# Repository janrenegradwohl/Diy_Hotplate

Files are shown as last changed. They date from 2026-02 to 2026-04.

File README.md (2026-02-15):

# DIY HotPlate

I needed a reflow hot plate for reflow-soldering, so I decided to build one myself. I used an STM32F301, which is connected to the PC via a USB-UART bridge. I’ve already ordered the second revision of the hardware.

I’m currently working on the hardware and firmware. PC software for control and data plotting will follow soon.

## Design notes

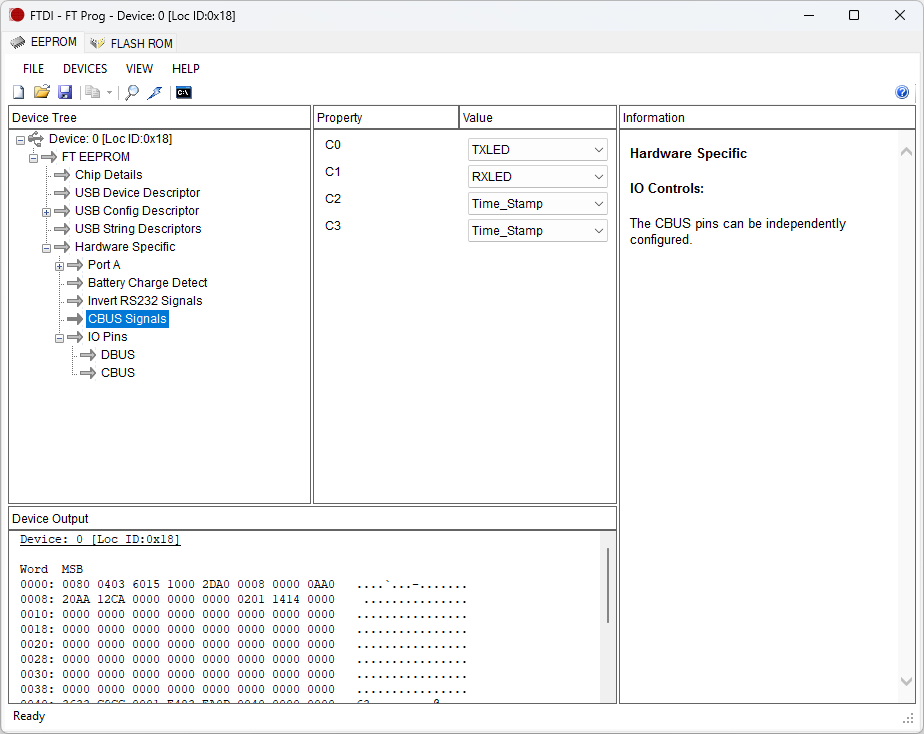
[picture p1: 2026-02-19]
pictures/FT_Prog.png

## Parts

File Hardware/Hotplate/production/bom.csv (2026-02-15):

Designator | Footprint | Quantity | Value | LCSC Part #
C1, C10, C2, C9 | 0603 | 4 | 100nF
C11, C6 | 0603 | 2 | 1uF
C12, C13 | 0603 | 2 | 47pF
C3 | 0603 | 1 | 10nF
C4, C5 | 0603 | 2 | 1uF | C15849
C7 | 0805 | 1 | 10uF | C15849
C8 | 0805 | 1 | 1uF | C15849
D1 | 0603 | 1 | 5V
D2, D3 | 0603 | 2 | LED
D4 | 0603 | 1 | 3V3
D5 | 0603 | 1 | PB7
D6 | 0603 | 1 | PA15
D7 | D_DO-15_P10.16mm_Horizontal | 1 | D_Schottky
IC1 | TO254P470X1016X1965-3P | 1 | TL783CKCSE3
IC2 | SOT95P270X145-5N | 1 | MCP1402T-E_OT
IC4 | SOP64P599X175-20N | 1 | FT231XS-U
J1, J2 | PinHeader_1x04_P2.54mm_Vertical | 2 | Conn_01x04_Pin
J10 | PinHeader_1x02_P2.54mm_Vertical | 1 | 5V
J3 | PinHeader_1x04_P2.54mm_Vertical | 1 | I2C2
J4 | SolderWire-1.5sqmm_1x01_D1.7mm_OD3mm | 1 | VCC
J5 | SolderWire-1.5sqmm_1x01_D1.7mm_OD3mm | 1 | GND
J8 | GSB1C41110SSHR | 1 | GSB1C41110SSHR
J9 | PinHeader_1x05_P2.54mm_Vertical | 1 | SPI3
Q1 | BSC146N10LS5ATMA1 | 1 | BSC146N10LS5ATMA1
R1, R17, R8, R9 | 0603 | 4 | 1k
R11, R15, R16 | 0603 | 3 | 270
R12, R13 | 0603 | 2 | 27
R4, R5 | 0805 | 2 | 15kR | C17475
R6 | 0805 | 1 | 4.7k
R7 | 0805 | 1 | 3k
SW1, SW2, SW3, SW4 | SW_PUSH_6mm | 4 | SW_Push
U1 | LQFP-32_7x7mm_P0.8mm | 1 | STM32F301K6Tx

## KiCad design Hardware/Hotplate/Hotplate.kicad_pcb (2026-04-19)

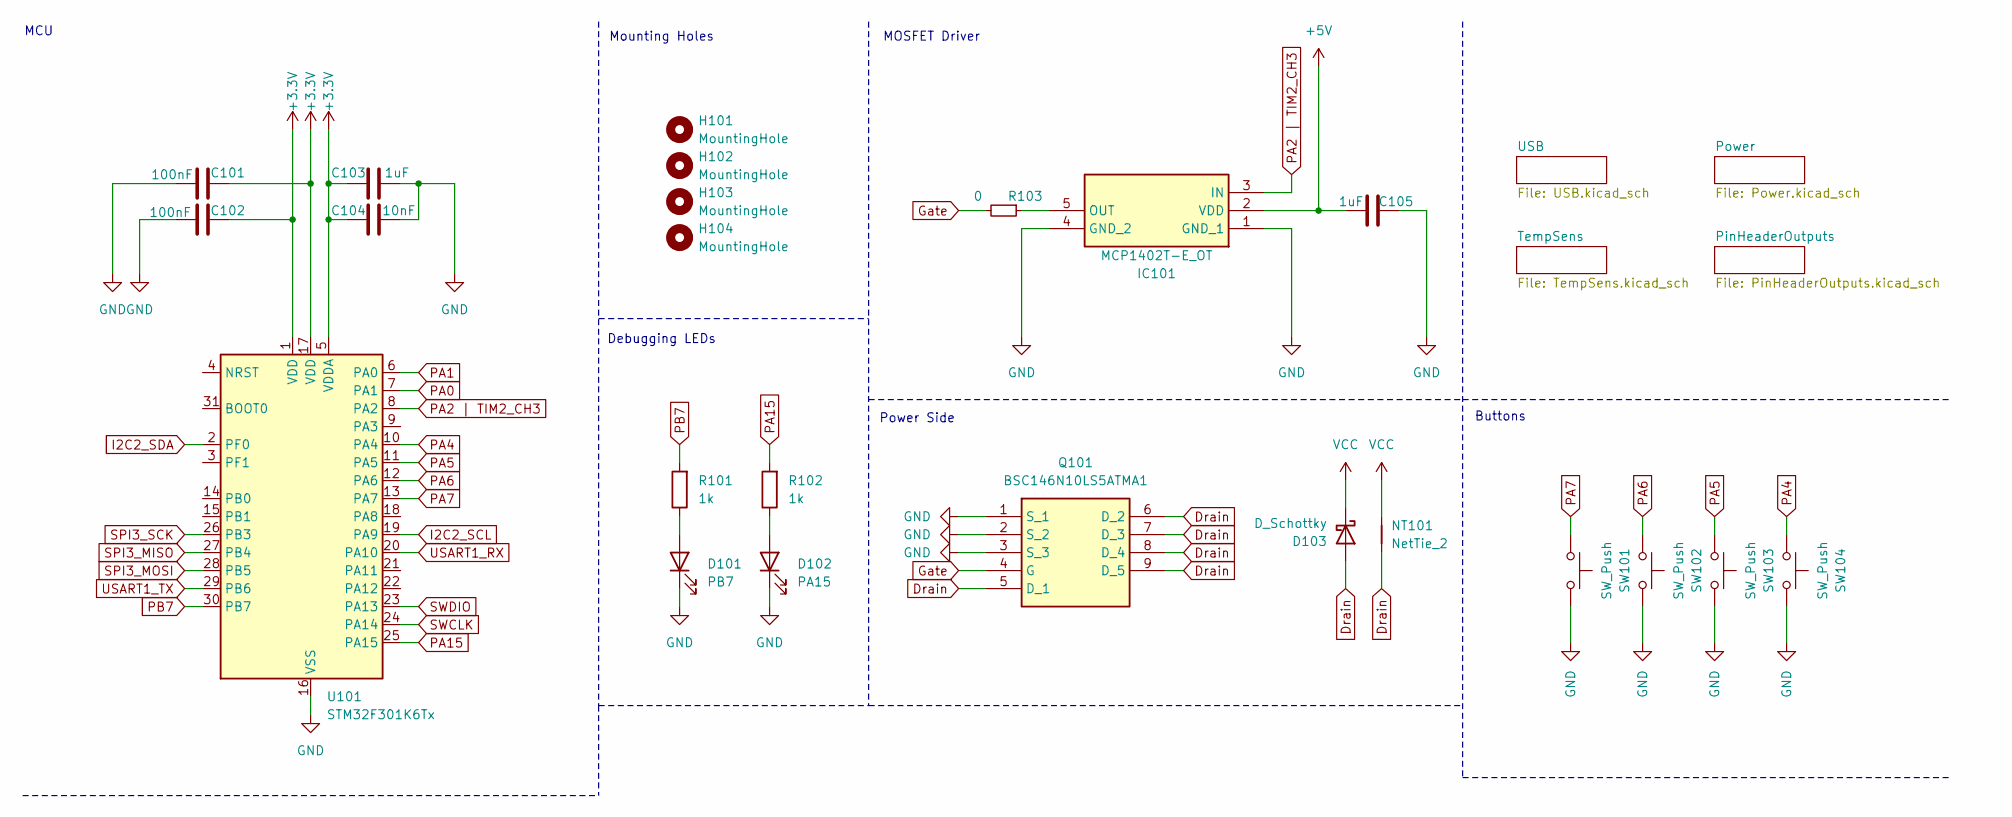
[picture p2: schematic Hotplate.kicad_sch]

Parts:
C101, C102: 100nF; C_0603_1608Metric
C103, C105: 1uF; C_0603_1608Metric
C104: 10nF; C_0603_1608Metric
D101: PB7; LED_0603_1608Metric_Pad1.05x0.95mm_HandSolder
D102: PA15; LED_0603_1608Metric_Pad1.05x0.95mm_HandSolder
D103: D_Schottky; D_DO-15_P10.16mm_Horizontal
H101, H102, H103, H104: MountingHole; MountingHole_2.7mm_M2.5
IC101: MCP1402T-E_OT; SOT95P270X145-5N; Mouser Part Number 579-MCP1402T-E/OT
NT101: NetTie_2; NetTie-2_SMD_Pad2.0mm
Q101: BSC146N10LS5ATMA1; Mouser Part Number 726-BSC146N10LS5ATMA
R101, R102: 1k; R_0603_1608Metric_Pad0.98x0.95mm_HandSolder
R103: 0; R_0603_1608Metric_Pad0.98x0.95mm_HandSolder
SW101, SW102, SW103, SW104: SW_Push; SW_PUSH_6mm
U101: STM32F301K6Tx; LQFP-32_7x7mm_P0.8mm

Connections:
+3.3V: C101.2, C102.2, C103.2, C104.2, U101.1 (VDD), U101.5 (VDDA), U101.17 (VDD); also elsewhere on the board
+5V: C105.2, IC101.2 (VDD); also elsewhere on the board
Drain: D103.2 (A), NT101.1, Q101.5 (D_1), Q101.6 (D_2), Q101.7 (D_3), Q101.8 (D_4), Q101.9 (D_5)
GND: C101.1, C102.1, C103.1, C104.1, C105.1, D101.1 (K), D102.1 (K), IC101.1 (GND_1), IC101.4 (GND_2), Q101.1 (S_1), Q101.2 (S_2), Q101.3 (S_3), SW101.2, SW102.2, SW103.2, SW104.2, U101.16 (VSS), U101.32 (VSS); also elsewhere on the board
Gate: Q101.4 (G), R103.2
I2C2_SCL: U101.19 (PA9); also elsewhere on the board
I2C2_SDA: U101.2 (PF0); also elsewhere on the board
unnamed: D101.2 (A), R101.1
unnamed: D102.2 (A), R102.1
unnamed: IC101.5 (OUT), R103.1
PA0: U101.7 (PA1); also elsewhere on the board
PA1: U101.6 (PA0); also elsewhere on the board
PA2 | TIM2_CH3: IC101.3 (IN), U101.8 (PA2)
PA4: SW104.1, U101.10 (PA4)
PA5: SW103.1, U101.11 (PA5)
PA6: SW102.1, U101.12 (PA6)
PA7: SW101.1, U101.13 (PA7)
PA15: R102.2, U101.25 (PA15)
PB7: R101.2, U101.30 (PB7)
SPI3_MISO: U101.27 (PB4); also elsewhere on the board
SPI3_MOSI: U101.28 (PB5); also elsewhere on the board
SPI3_SCK: U101.26 (PB3); also elsewhere on the board
SWCLK: U101.24 (PA14); also elsewhere on the board
SWDIO: U101.23 (PA13); also elsewhere on the board
USART1_RX: U101.20 (PA10); also elsewhere on the board
USART1_TX: U101.29 (PB6); also elsewhere on the board
VCC: D103.1 (K), NT101.2; also elsewhere on the board

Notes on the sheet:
MOSFET Driver
Mounting Holes
MCU
Buttons
Debugging LEDs
Power Side

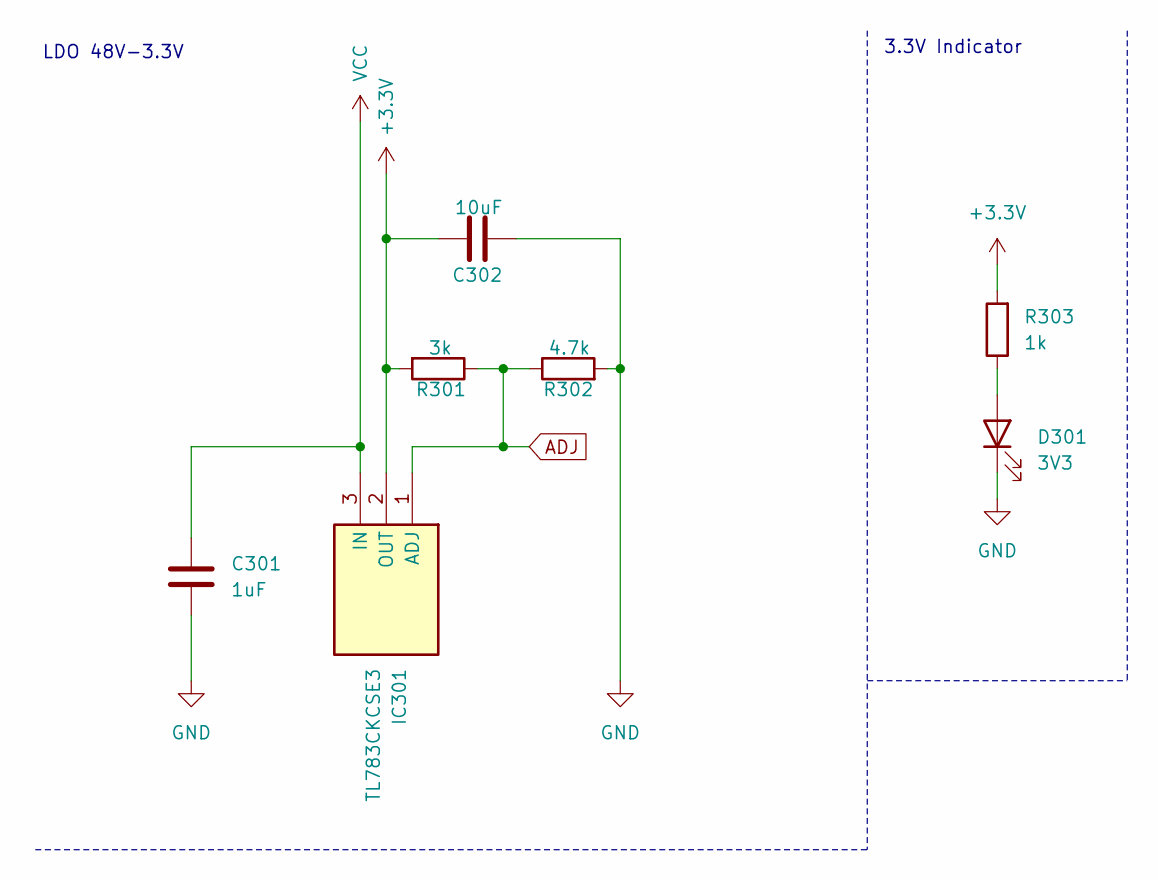
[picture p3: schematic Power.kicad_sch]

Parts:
C301: 1uF; C_0805_2012Metric; LCSC C15849
C302: 10uF; C_0805_2012Metric; LCSC C15849
D301: 3V3; LED_0603_1608Metric_Pad1.05x0.95mm_HandSolder
IC301: TL783CKCSE3; TO254P470X1016X1965-3P; Mouser Part Number 595-TL783CKCSE3
R301: 3k; R_0805_2012Metric
R302: 4.7k; R_0805_2012Metric
R303: 1k; R_0603_1608Metric_Pad0.98x0.95mm_HandSolder

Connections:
+3.3V: C302.2, IC301.2 (OUT), R301.2, R303.2; also elsewhere on the board
ADJ: IC301.1 (ADJ), R301.1, R302.1
GND: C301.2, C302.1, D301.1 (K), R302.2; also elsewhere on the board
unnamed: D301.2 (A), R303.1
VCC: C301.1, IC301.3 (IN); also elsewhere on the board

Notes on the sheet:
LDO 48V-3.3V
3.3V Indicator

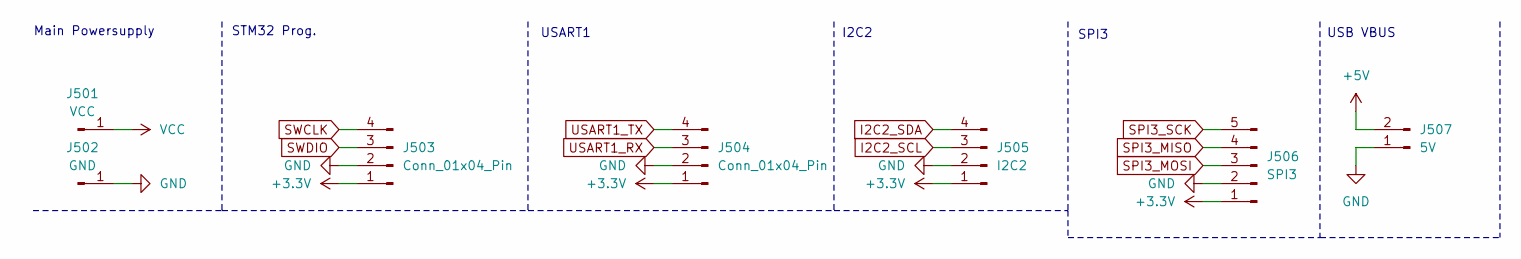
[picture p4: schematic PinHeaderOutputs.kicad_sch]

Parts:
J501: VCC; SolderWire-1.5sqmm_1x01_D1.7mm_OD3mm
J502: GND; SolderWire-1.5sqmm_1x01_D1.7mm_OD3mm
J503, J504: Conn_01x04_Pin; PinHeader_1x04_P2.54mm_Vertical
J505: I2C2; PinHeader_1x04_P2.54mm_Vertical
J506: SPI3; PinHeader_1x05_P2.54mm_Vertical
J507: 5V; PinHeader_1x02_P2.54mm_Vertical

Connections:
+3.3V: J503.1, J504.1, J505.1, J506.1; also elsewhere on the board
+5V: J507.2; also elsewhere on the board
GND: J502.1, J503.2, J504.2, J505.2, J506.2, J507.1; also elsewhere on the board
I2C2_SCL: J505.3; also elsewhere on the board
I2C2_SDA: J505.4; also elsewhere on the board
SPI3_MISO: J506.4; also elsewhere on the board
SPI3_MOSI: J506.3; also elsewhere on the board
SPI3_SCK: J506.5; also elsewhere on the board
SWCLK: J503.4; also elsewhere on the board
SWDIO: J503.3; also elsewhere on the board
USART1_RX: J504.3; also elsewhere on the board
USART1_TX: J504.4; also elsewhere on the board
VCC: J501.1; also elsewhere on the board

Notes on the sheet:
Main Powersupply
I2C2
SPI3
STM32 Prog.
USB VBUS
USART1

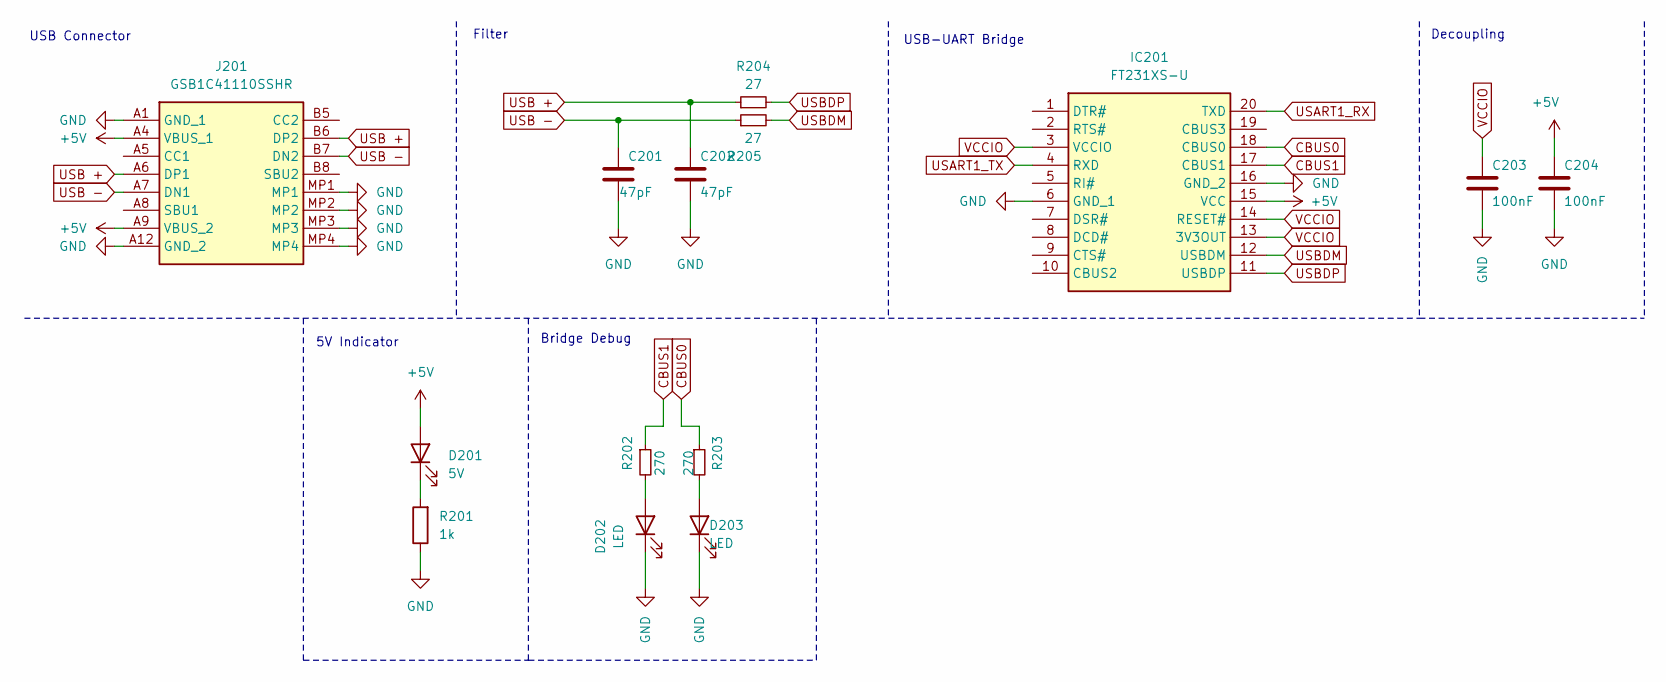
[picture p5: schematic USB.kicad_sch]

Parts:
C201, C202: 47pF; C_0603_1608Metric_Pad1.08x0.95mm_HandSolder
C203, C204: 100nF; C_0603_1608Metric_Pad1.08x0.95mm_HandSolder
D201: 5V; LED_0603_1608Metric_Pad1.05x0.95mm_HandSolder
D202, D203: LED; LED_0603_1608Metric_Pad1.05x0.95mm_HandSolder
IC201: FT231XS-U; SOP64P599X175-20N; Mouser Part Number 895-FT231XS-U
J201: GSB1C41110SSHR; Manufacturer_Part_Number GSB1C41110SSHR
R201: 1k; R_0603_1608Metric_Pad0.98x0.95mm_HandSolder
R202, R203: 270; R_0603_1608Metric_Pad0.98x0.95mm_HandSolder
R204, R205: 27; R_0603_1608Metric_Pad0.98x0.95mm_HandSolder

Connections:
+5V: C204.1, D201.2 (A), IC201.15 (VCC), J201.A4 (VBUS_1), J201.A9 (VBUS_2); also elsewhere on the board
CBUS0: IC201.18 (CBUS0), R203.1
CBUS1: IC201.17 (CBUS1), R202.1
GND: C201.2, C202.2, C203.2, C204.2, D202.1 (K), D203.1 (K), IC201.6 (GND_1), IC201.16 (GND_2), J201.A1 (GND_1), J201.A12 (GND_2), J201.MP1, J201.MP2, J201.MP3, J201.MP4, R201.1; also elsewhere on the board
unnamed: D201.1 (K), R201.2
unnamed: D202.2 (A), R202.2
unnamed: D203.2 (A), R203.2
USART1_RX: IC201.20 (TXD); also elsewhere on the board
USART1_TX: IC201.4 (RXD); also elsewhere on the board
USB +: C202.1, J201.A6 (DP1), J201.B6 (DP2), R204.1
USB -: C201.1, J201.A7 (DN1), J201.B7 (DN2), R205.1
USBDM: IC201.12 (USBDM), R205.2
USBDP: IC201.11 (USBDP), R204.2
VCCIO: C203.1, IC201.3 (VCCIO), IC201.13 (3V3OUT), IC201.14 (RESET#)

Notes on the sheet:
Filter
USB-UART Bridge
Bridge Debug
Decoupling
USB Connector
5V Indicator

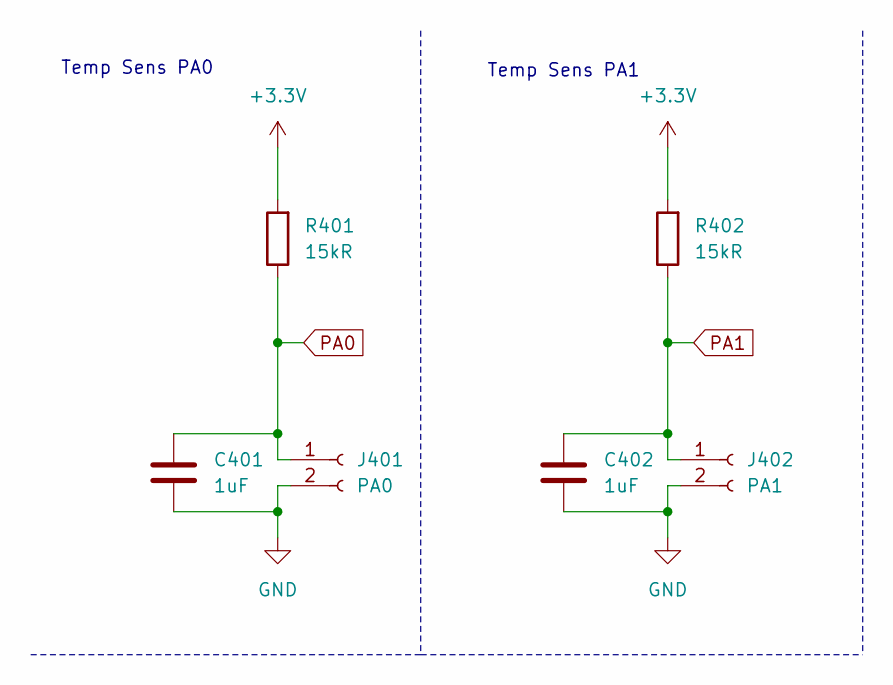
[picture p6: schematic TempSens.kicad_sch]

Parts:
C401, C402: 1uF; C_0603_1608Metric; LCSC C15849
J401: PA0; JST_EH_B2B-EH-A_1x02_P2.50mm_Vertical
J402: PA1; JST_EH_B2B-EH-A_1x02_P2.50mm_Vertical
R401, R402: 15kR; R_0805_2012Metric; LCSC C17475

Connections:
+3.3V: R401.2, R402.2; also elsewhere on the board
GND: C401.2, C402.2, J401.2, J402.2; also elsewhere on the board
PA0: C401.1, J401.1, R401.1; also elsewhere on the board
PA1: C402.1, J402.1, R402.1; also elsewhere on the board

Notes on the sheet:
Temp Sens PA1
Temp Sens PA0

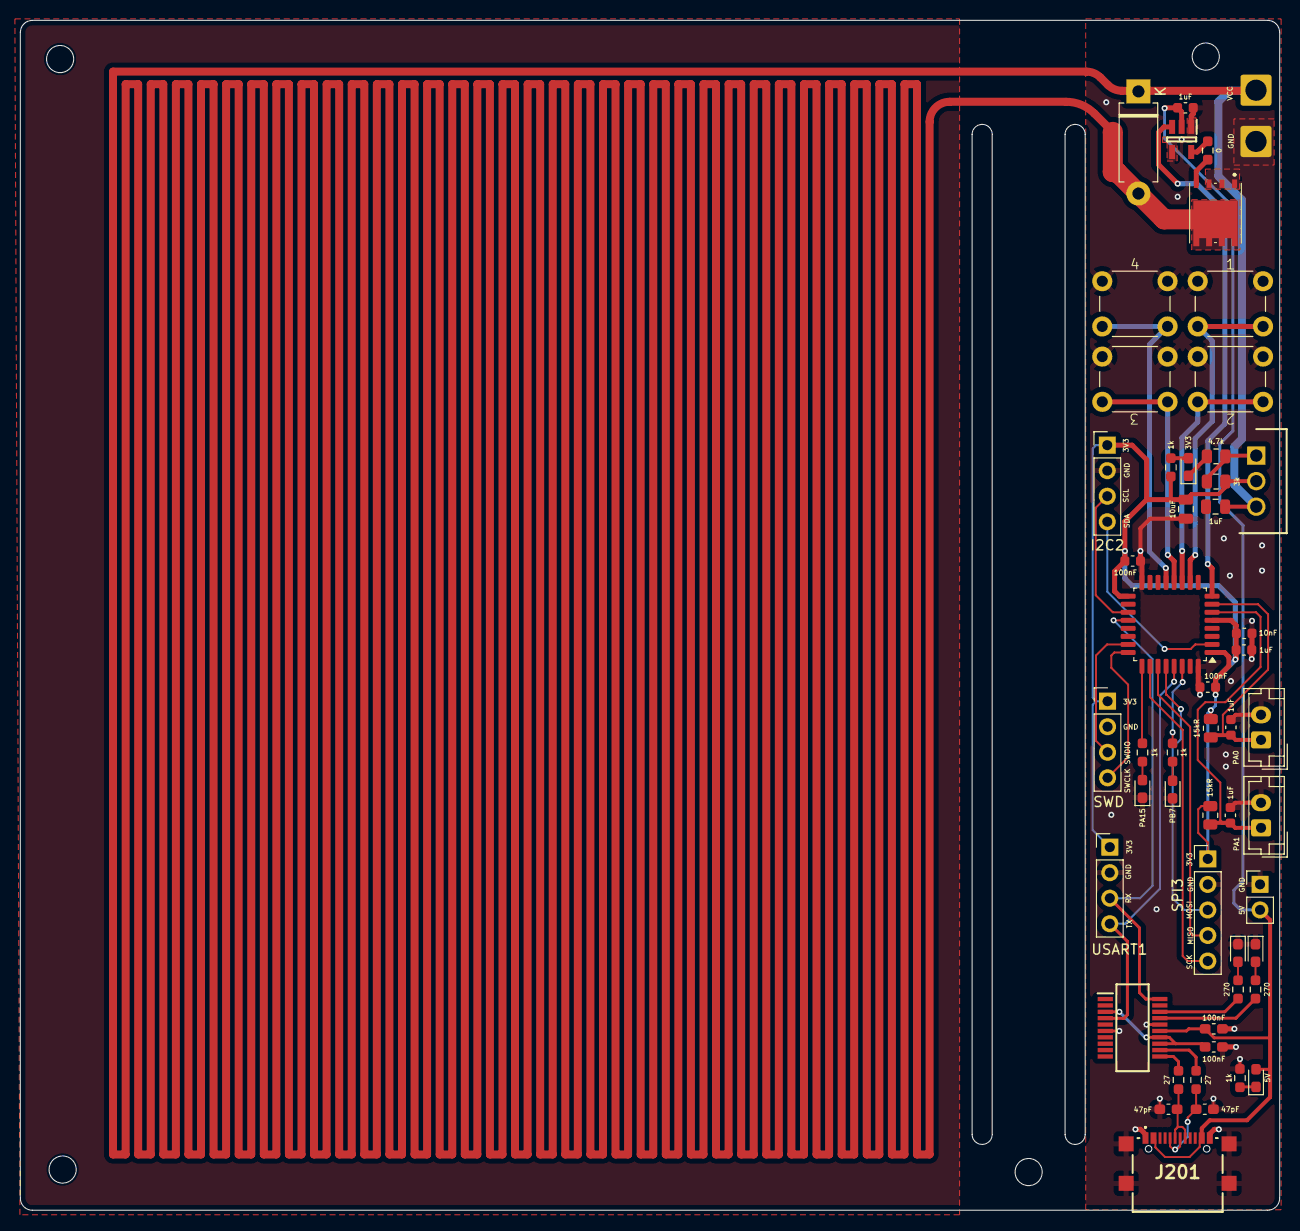
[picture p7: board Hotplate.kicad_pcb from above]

Board: 2 copper layers, 125.3 x 118.4 mm, 57 parts (0 on the bottom side), 39 nets.

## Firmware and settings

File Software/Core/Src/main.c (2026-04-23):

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
/* Includes ------------------------------------------------------------------*/
#include "main.h"
#include "adc.h"
#include "dma.h"
#include "tim.h"
#include "usart.h"
#include "gpio.h"

/* USER CODE BEGIN Includes */
#include "pid.h"
#include <math.h>
#include <stdio.h>
#include <string.h>
#include <pid.h>
/* USER CODE END Includes */


void SystemClock_Config(void);
/* USER CODE BEGIN PFP */
float ntc_get_temperature(uint32_t adc_value);
/* USER CODE END PFP */

/* USER CODE BEGIN 0 */

#define ADC1_RES     4095.0    // Auflösung (12 Bit: 2^12 - 1)
#define R_Seri_T       6800.0	//
#define A_COEFF_T     0.0924917  // a in Ohm
#define B_COEFF_T     4135.86     // b in Kelvin 4135.86
#define BUFFER_SIZE 64

uint32_t PWM_Duty_T2C3 = 1;

int pispeed[5] = { 1, 10, 20, 100, 500 };
volatile uint32_t ADC1_Reading[2] = { 0, 0 };
volatile uint32_t temp_data = 1;
volatile uint32_t m_tim1_set_value = 0;
const float t_kp = 0.08;
const float t_ki = 0.002;
const float t_kd = 0.0001;
volatile float t_imem;
volatile float t_previous_measurement = 0;
volatile uint32_t t_value;

//uint8_t HeatMode = 0b00000000;
float TempSetPoint = 0;

char UART_pData_TX[BUFFER_SIZE];
char UART_pData_RX[BUFFER_SIZE];
char DMA_BUFFER[BUFFER_SIZE];

volatile uint16_t globalTime = 0;
volatile uint16_t globalLastTime = 0;
volatile uint16_t globalElapsedTime = 0;
volatile uint16_t lastTime = 0;

//uint32_t tempAddLastTime = 0;
//uint32_t tempAddTimer = 10; 		//temperature add timer
//uint16_t tempSetValue = 20;			//20°C
//uint16_t tempMaxValue = 150;	//defines max temperature value, init with 150°C

/* USER CODE END 0 */

/**
  * @brief  The application entry point.
  * @retval int
  */
int main(void)
{

  /* MCU Configuration--------------------------------------------------------*/

  /* Reset of all peripherals, Initializes the Flash interface and the Systick. */
  HAL_Init();

  /* USER CODE BEGIN Init */


	PID_f temp_pid;
	pid_begin(&temp_pid, t_kp, t_ki, t_kd, 255, 0, t_previous_measurement, t_imem);
  /* USER CODE END Init */

  /* Configure the system clock */
  SystemClock_Config();

  /* Initialize all configured peripherals */
  MX_GPIO_Init();
  MX_DMA_Init();
  MX_ADC1_Init();
  MX_TIM2_Init();
  MX_TIM1_Init();
  MX_USART1_UART_Init();
  MX_TIM15_Init();
  MX_TIM6_Init();
  /* Infinite loop */
  /* USER CODE BEGIN WHILE */

	HAL_TIM_Base_Start(&htim1);
	HAL_TIM_Base_Start(&htim6); // runs on 1000Hz update rate
	HAL_TIM_PWM_Start(&htim2, TIM_CHANNEL_3);
	HAL_ADCEx_Calibration_Start(&hadc1, ADC_SINGLE_ENDED);
	HAL_ADC_Start_DMA(&hadc1, (uint32_t*) ADC1_Reading, 2);

	//temp_pi.setpoint = pispeed[2];
	temp_pid.setpoint = 100;
	TIM2->CCR3 = PWM_Duty_T2C3;

	while (1) {
		globalLastTime = __HAL_TIM_GET_COUNTER(&htim6);
		HAL_GPIO_TogglePin(GPIOA, GPIO_PIN_15);

		t_value = ADC1_Reading[0];
		temp_pid.measurement = ntc_get_temperature(t_value);
		sprintf(DMA_BUFFER, "Reg: %i, Temp [°C]; %i, ElapsedTime [us]; %i, PWM [DC]; %i\n\r",
				(int) t_value, (int) ntc_get_temperature(t_value),(int) globalElapsedTime, (int) temp_pid.output);

		pid_parallel_t(&temp_pid, (float) globalElapsedTime/1000.0f); //globalElapsedTime/1000.0f
		TIM2->CCR3 = (uint32_t) temp_pid.output;

		HAL_UART_Transmit_DMA(&huart1, (uint8_t*) DMA_BUFFER,
				strlen(DMA_BUFFER));
		HAL_Delay(1);

		globalTime = __HAL_TIM_GET_COUNTER(&htim6);
		globalElapsedTime = globalTime - globalLastTime;

    /* USER CODE END WHILE */

    /* USER CODE BEGIN 3 */
	}
  /* USER CODE END 3 */
}

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
/* USER CODE BEGIN 4 */

float ntc_get_temperature(uint32_t adc_value) {

        float V = (adc_value / ADC1_RES) * 3.3;
        float R_ntc = R_Seri_T * (V / (3.3 - V));

        float lnR = logf(R_ntc);
        float lnA = logf(A_COEFF_T);

        float T_K = B_COEFF_T / (lnR - lnA);  // Temperatur in Kelvin
        float T_C = T_K - 273.15;           // in °C umrechnen

        return T_C;
    }
/* USER CODE END 4 */
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


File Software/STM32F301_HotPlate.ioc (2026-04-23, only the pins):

Mcu.UserName=STM32F301K6Tx
PA0.Signal=ADC1_IN1
PA1.Signal=ADC1_IN2
PA10.Signal=USART1_RX
PA13.Signal=SYS_JTMS-SWDIO
PA14.Signal=SYS_JTCK-SWCLK
PA15.GPIO_Label=D6
PA15.Signal=GPIO_Output
PA2.Signal=S_TIM2_CH3
PA4.GPIO_Label=B1
PA4.Signal=GPIO_Output
PA5.GPIO_Label=B2
PA5.Signal=GPIO_Output
PA6.GPIO_Label=B3
PA6.Signal=GPIO_Input
PA7.GPIO_Label=B4
PA7.Signal=GPIO_Input
PB6.Signal=USART1_TX
PB7.GPIO_Label=D5
PB7.Signal=GPIO_Output

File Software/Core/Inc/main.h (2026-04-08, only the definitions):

#define B1_Pin GPIO_PIN_4
#define B1_GPIO_Port GPIOA
#define B2_Pin GPIO_PIN_5
#define B2_GPIO_Port GPIOA
#define B3_Pin GPIO_PIN_6
#define B3_GPIO_Port GPIOA
#define B4_Pin GPIO_PIN_7
#define B4_GPIO_Port GPIOA
#define D6_Pin GPIO_PIN_15
#define D6_GPIO_Port GPIOA
#define D5_Pin GPIO_PIN_7
#define D5_GPIO_Port GPIOB

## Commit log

2026-02-17 Tested PCB V2
2026-02-17 Deleted PCB BackUps
2026-02-24 Updated Kicad 8 to 9
    [Hotplate.kicad_pcb, Hotplate.kicad_sch, PinHeaderOutputs.kicad_sch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]
2026-03-03 added Timer (#7)
2026-03-10 made it pretty (#8)
    [Hotplate.kicad_pcb, Hotplate.kicad_sch, PinHeaderOutputs.kicad_sch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]
2026-03-10 debugged, tim6 error (#9)
    [STM32F301_HotPlate.ioc, main.c]
2026-03-24 Debbuged, tempsense error (#11)
    [STM32F301_HotPlate.ioc, main.c]
2026-04-07 fixed:ADC reading (#12)
2026-04-08 fixed:flashsize(buildinrelease), fixed:tim6, fixed:tim1 (#13)
    [STM32F301_HotPlate.ioc, main.c]
2026-04-15 error: PID (#14)
2026-04-19 Debug (#15)
    * fixed:PID
    * fixed:PID
    * fixed:dyingFETs
    [Hotplate.kicad_pcb, Hotplate.kicad_sch]
2026-04-23 Debugged: FETDriver too slow (#16)
    [STM32F301_HotPlate.ioc, main.c]

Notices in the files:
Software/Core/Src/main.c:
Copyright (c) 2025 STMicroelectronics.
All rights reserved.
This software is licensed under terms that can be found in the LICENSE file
